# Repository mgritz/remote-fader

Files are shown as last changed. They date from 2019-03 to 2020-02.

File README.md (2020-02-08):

# Remote Fader Firmware for the Datasat AP20 Digital Cinema Audio Processor

## Why is this here?

_Skip if you don't care about fluff._

Well, easy. During my days in university I joined the student cinema group.
As it happened in those days I was able to contribute to the major task of
replacing the outdated analog projection equipment in our theatre with more
up-to-date equipment. Along with a digital projector and some other equipment
we acquired a new Datasat AP20 audio processor.

Long story short, we needed a simple rotary knob _inside_ the cinema theatre for
the supervisor to control the overall volume during a film show while the actual
audio processor sits upstairs in the projector room. Buying the knob from
Datasat was not an option simply because of the hefty price tag.

But we found that Datasat implements a rather simple ASCII based protocol to
handle a whole bunch of settings on their devices and the AP20 has several
interfaces we could use with RS232 being among those. So we traced a cable
through the building...

The first approach was a TI MSP430 Launchpad with an Alps rotary encoder knob
connected that single-directionally transmits ASCII commands to the AP20. But
would't it be cool to have something with also a display?

## What is this?

The coolest type of display we could come up with for a volume control knob to
be used in a dark room is a Nixie tube display.

The PCB in this project connects two digits of IN12b Nixie tubes to an
MSP430G2553. There are two galvanically isolated voltage domains to protect the 
expensive AP20 against surges from the make-shift high voltage supply of the
Nixies.

The application code mainly does two things:
1. Whenever the knob is turned a volume command 'FADER +x\r' is transmitted
   towards the AP20 via UART. That, in turn, causes the AP20 to respond...
2. ... with a 'FADER xx\r' string denominating the current volume level.
   The number is extracted and displayed on the nixies.

Due to poor (but for now, uncorrectable) PCB design choices there must be some
additional glue and safety around the I2C connection between the MSP and the
MAX GPIO expander IC on the other side of the voltage safety barrier.

## Building and Contributing

This is not tested yet and sort of a long running project of mine.
I am using TI Code Composer Studio 8.3 and TI MSP compiler v18.1.5 on Windows
and the programmer-part of the MSP430 Launchpad for debugging.

Documentation for the AP20 and other helpful stuff: \\
http://www.film-tech.com \\
http://www.film-tech.com/warehouse/manuals/TM-H392_V1.2_AP20.pdf

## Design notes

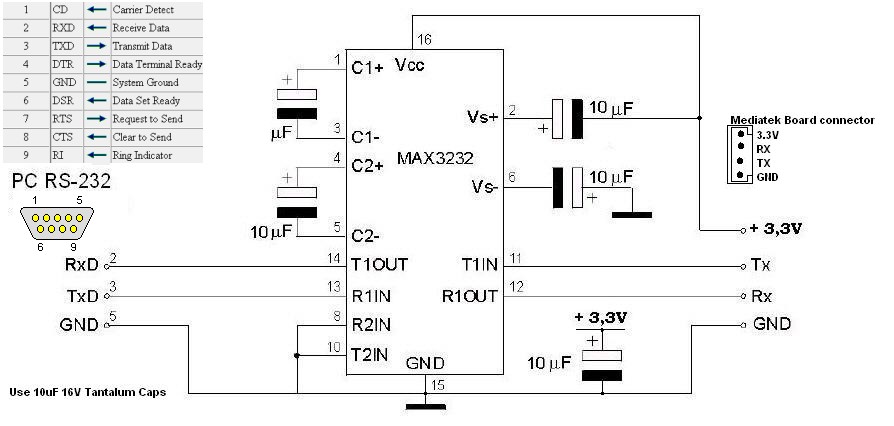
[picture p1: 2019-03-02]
circuit-boards/INTERFACE-MT1389.jpg

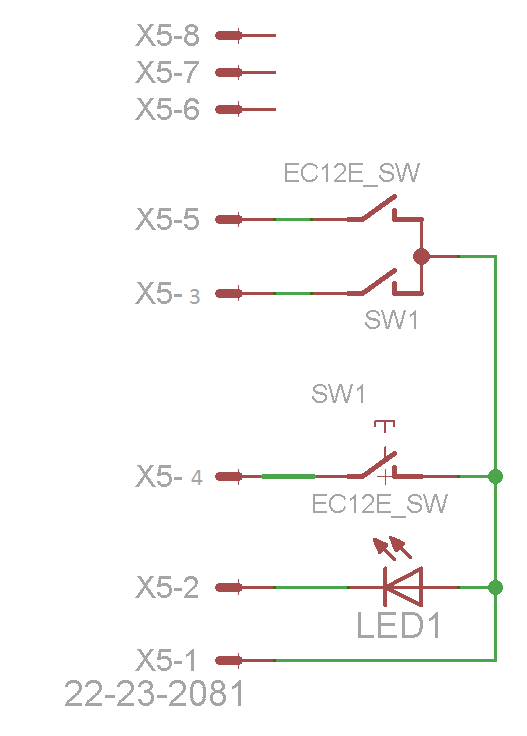
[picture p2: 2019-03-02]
circuit-boards/steckerbelegung.png

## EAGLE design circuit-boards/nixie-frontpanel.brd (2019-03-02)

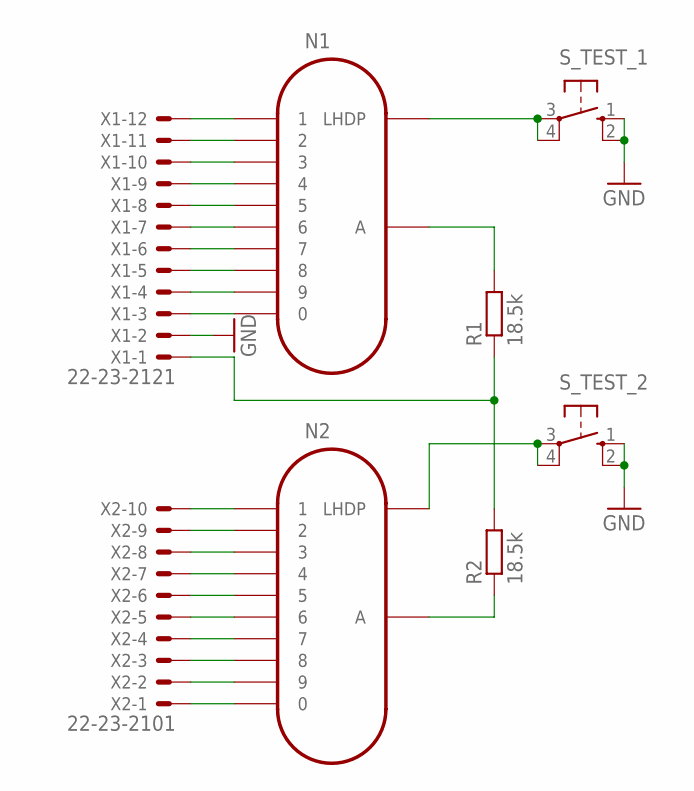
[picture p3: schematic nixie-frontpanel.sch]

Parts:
N1, N2: IN-12B; IN-12
R1, R2: 18.5k; M0805
S_TEST_1, S_TEST_2: 10-XX; B3F-10XX
X1: 22-23-2121
X2: 22-23-2101

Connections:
GND: S_TEST_1.1 (S), S_TEST_1.2 (S1), S_TEST_2.1 (S), S_TEST_2.2 (S1), X1.2
unnamed: N1.1, X1.12
unnamed: N1.2, X1.11
unnamed: N1.3, X1.10
unnamed: N1.4, X1.9
unnamed: N1.5, X1.8
unnamed: N1.6, X1.7
unnamed: N1.7, X1.6
unnamed: N1.8, X1.5
unnamed: N1.9, X1.4
unnamed: N1.0, X1.3
unnamed: N2.1, X2.10
unnamed: N2.2, X2.9
unnamed: N2.3, X2.8
unnamed: N2.4, X2.7
unnamed: N2.5, X2.6
unnamed: N2.6, X2.5
unnamed: N2.7, X2.4
unnamed: N2.8, X2.3
unnamed: N2.9, X2.2
unnamed: N2.0, X2.1
unnamed: R1.1, R2.2, X1.1
unnamed: N1.A, R1.2
unnamed: N2.A, R2.1
unnamed: N1.LHDP, S_TEST_1.3, S_TEST_1.4 (P1)
unnamed: N2.LHDP, S_TEST_2.3, S_TEST_2.4 (P1)

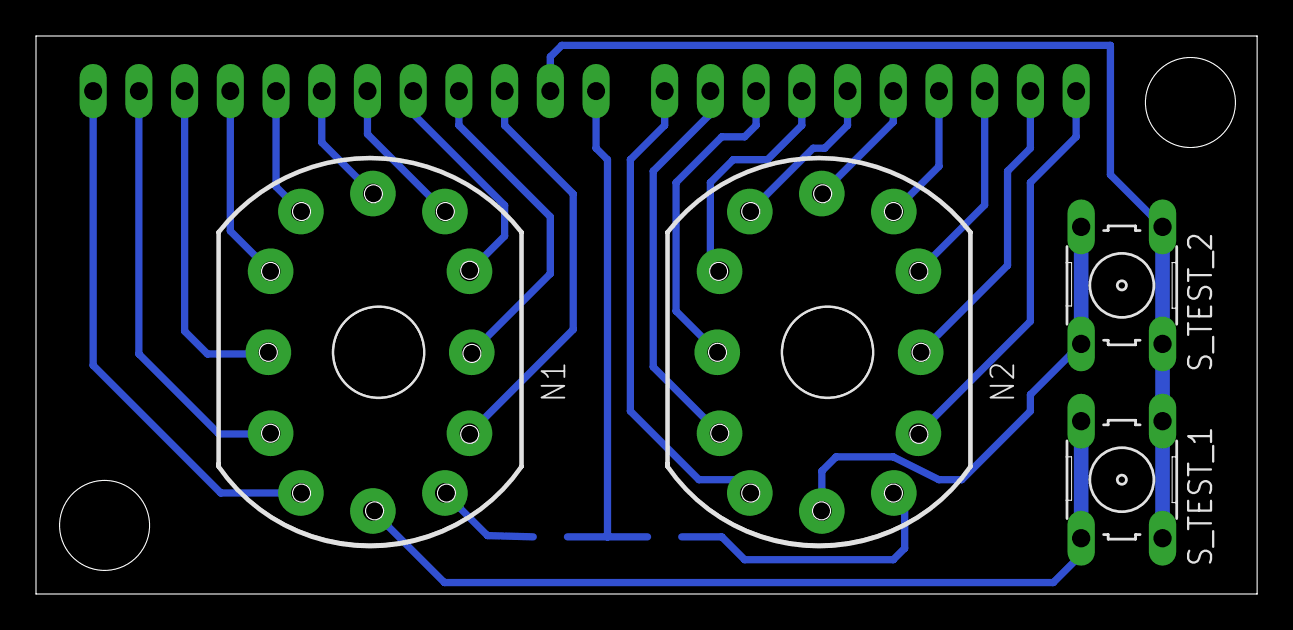
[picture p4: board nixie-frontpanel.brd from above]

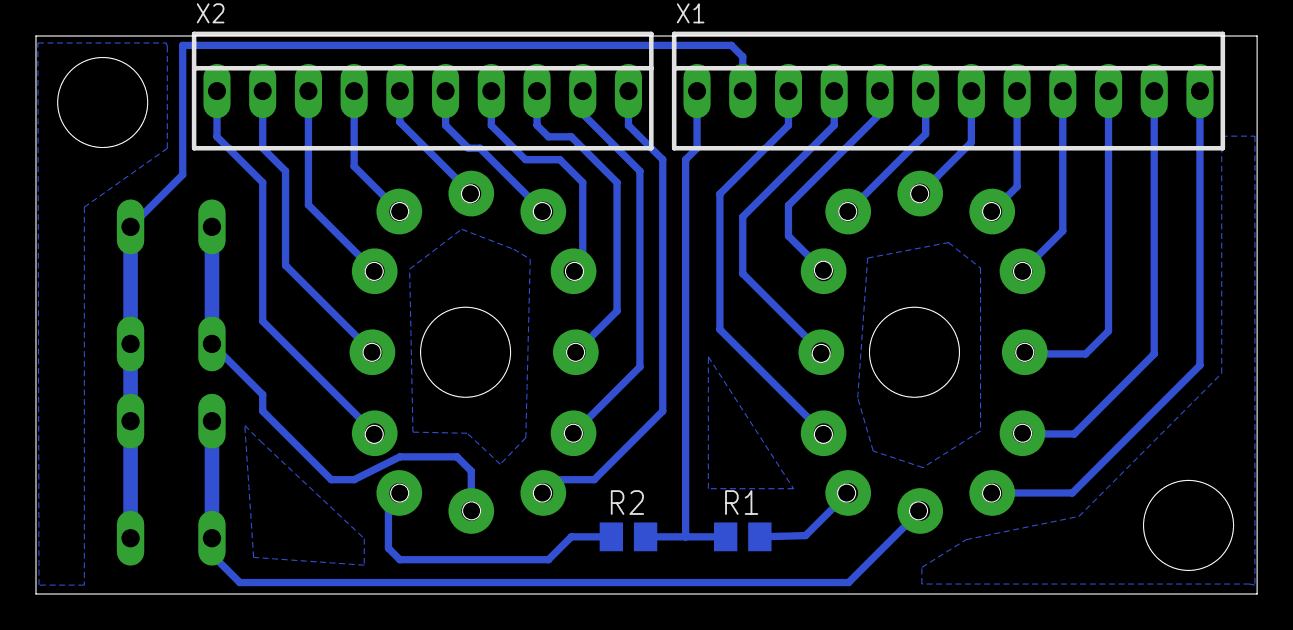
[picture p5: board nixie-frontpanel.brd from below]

Board: 2 copper layers, 67.8 x 31.0 mm, 8 parts (4 on the bottom side), 26 nets.

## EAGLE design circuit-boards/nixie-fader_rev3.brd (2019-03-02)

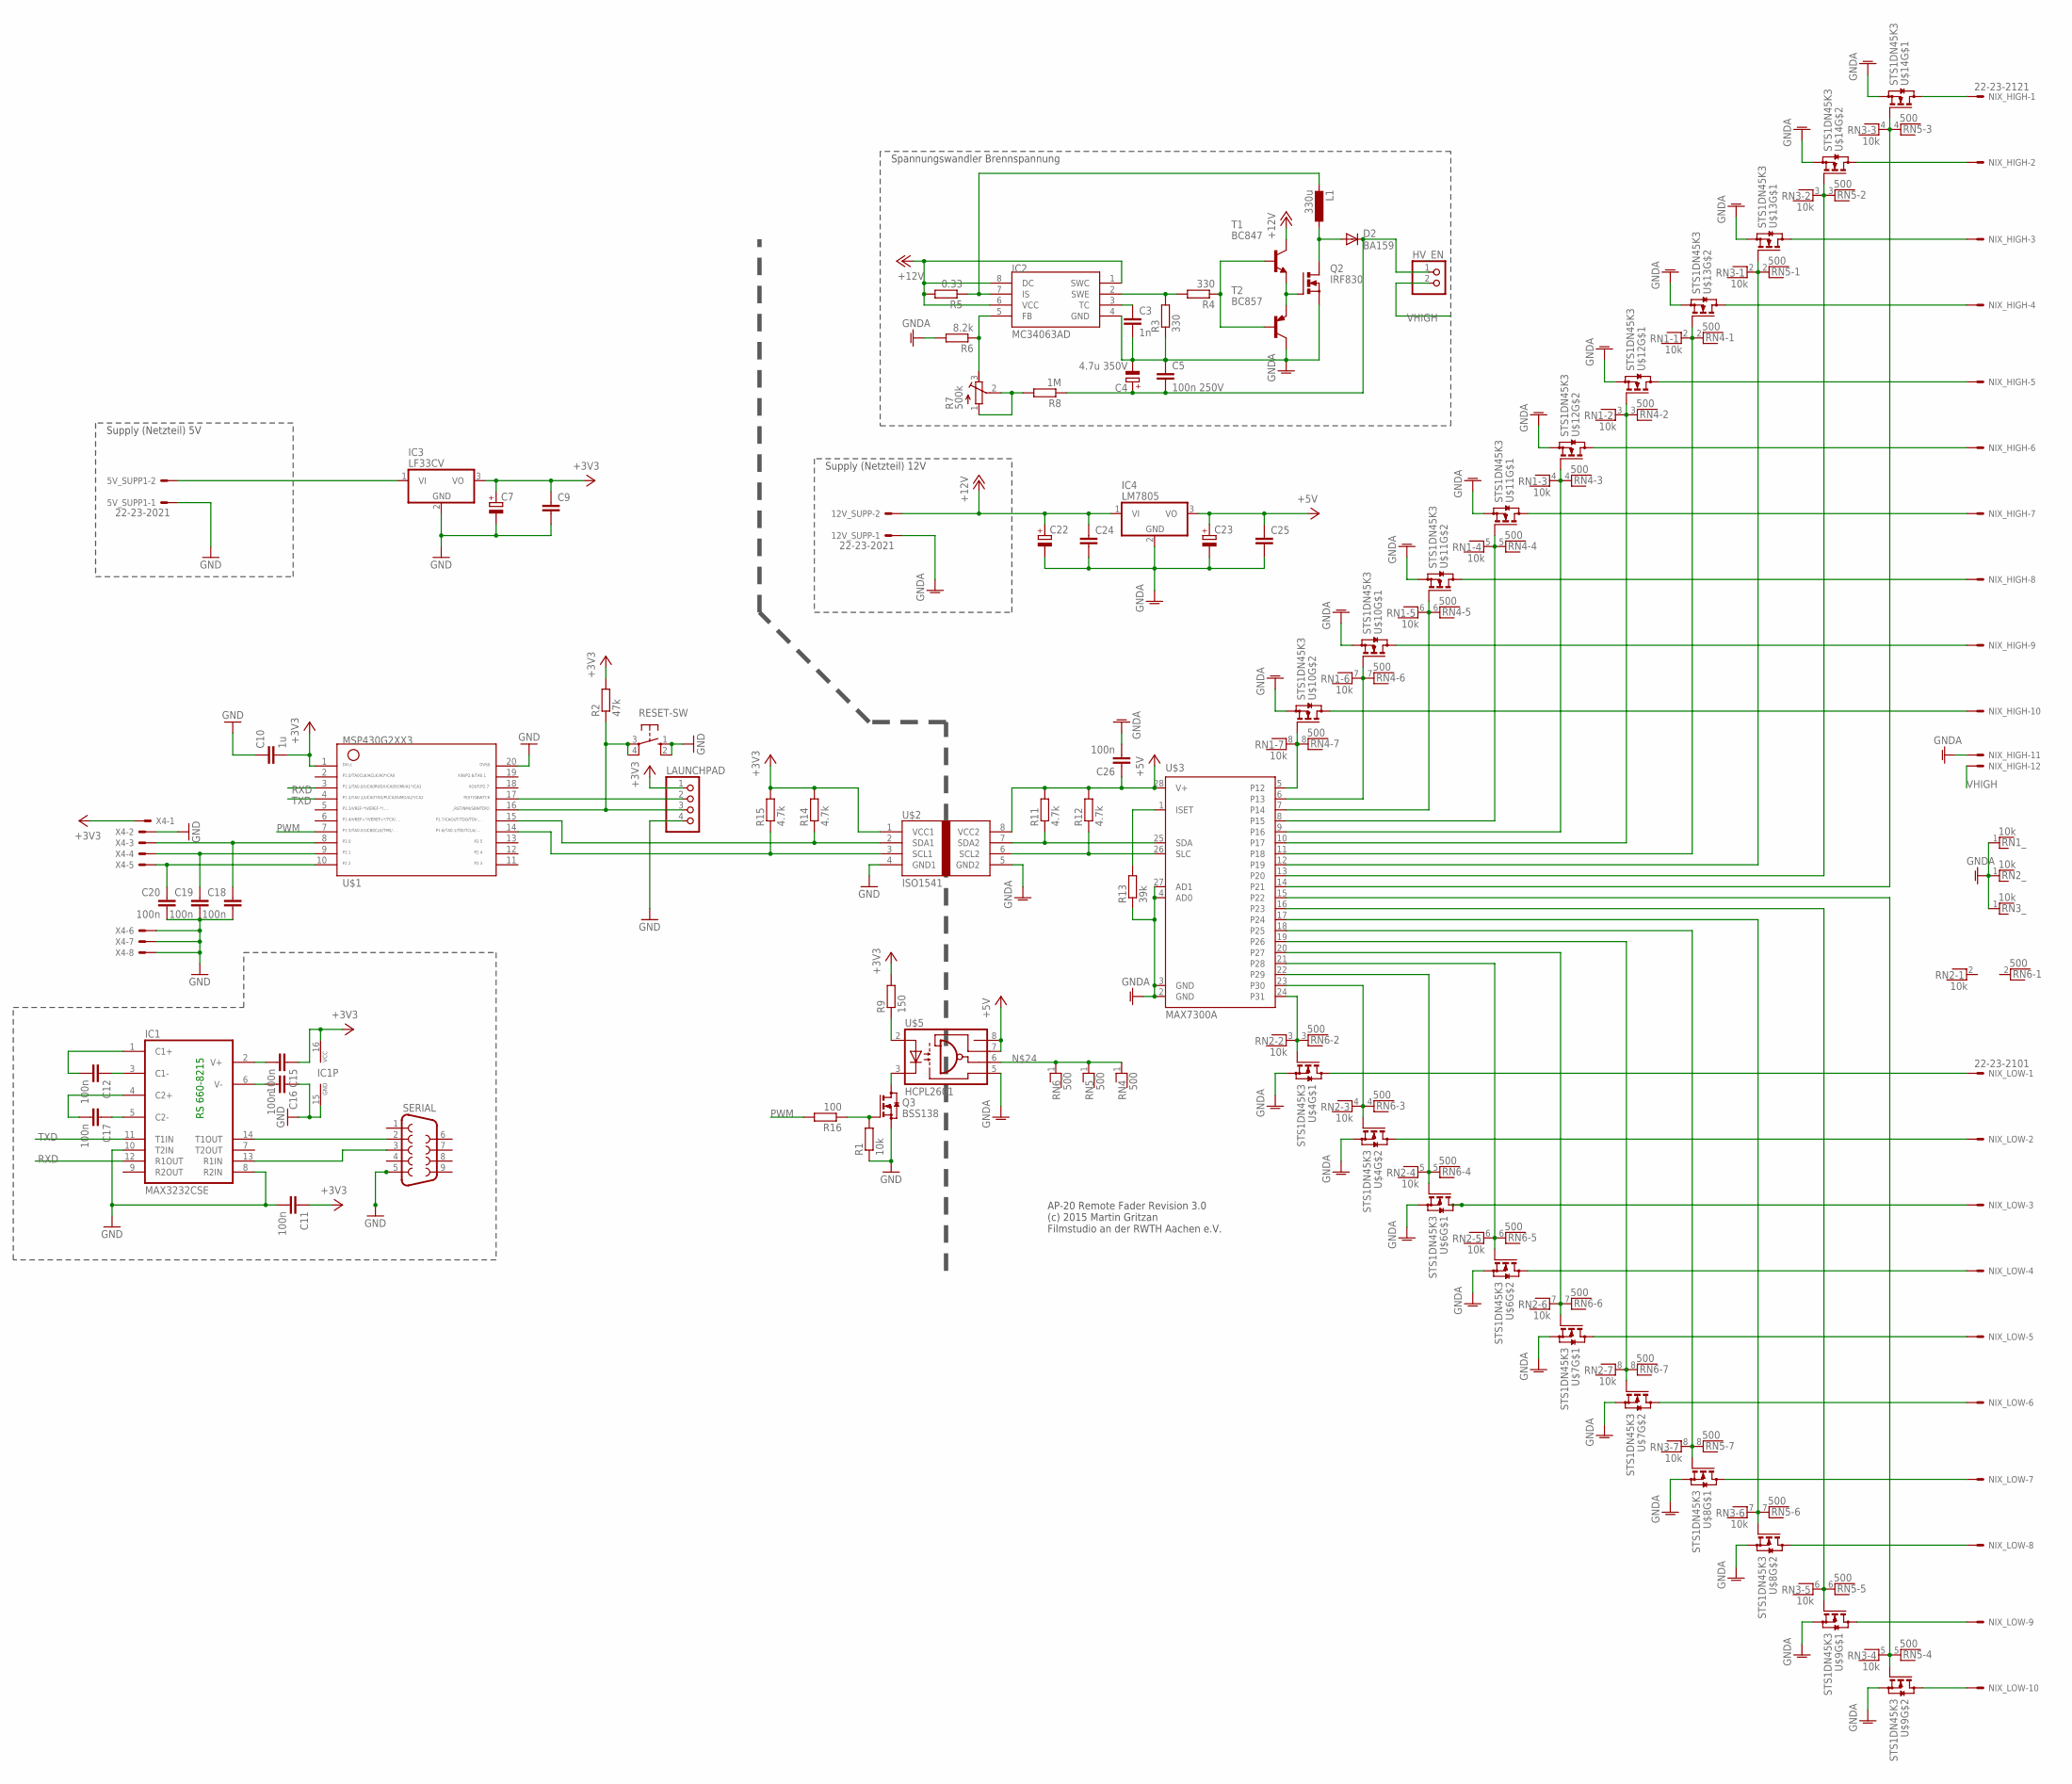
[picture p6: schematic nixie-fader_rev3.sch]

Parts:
5V_SUPP1, 12V_SUPP: 22-23-2021
C3: 1n; C0805
C4: 4.7u 350V; E5-8,5
C5: 100n 250V; C050-024X044
C7, C22, C23: CPOL-EU140CLH-0810; 140CLH-0810
C9, C24, C25: C-EUC0805K; C0805K
C10: 1u; C0805K
C11, C12, C15, C16, C17, C18, C19, C20, C26: 100n; C0805
D2: BA159; P1-10
HV_EN: PINHD-1X2; 1X02
IC1: MAX3232CSE; SO16
IC2: MC34063AD; SOIC8
IC3: LF33CV; TO220V
IC4: LM7805; TO220V
L1: 330u; IRF36
LAUNCHPAD: PINHD-1X4; 1X04
NIX_HIGH: 22-23-2121
NIX_LOW: 22-23-2101
Q2: IRF830; TO220BV
Q3: BSS138; SOT23
R1: 10k; M0805
R2: 47k; R0805
R3, R4: 330; M0805
R5: 0.33; M0805
R6: 8.2k; M0805
R7: 500k; RTRIM3296Y
R8: 1M; M0805
R9: 150; M0805
R11, R12, R14, R15: 4.7k; M0805
R13: 39k; M0805
R16: 100; M0805
RESET-SW: 10-XX; B3F-10XX
RN1, RN2, RN3: 10k; RN-8
RN4, RN5, RN6: 500; RN-8
SERIAL: F09H
T1: BC847; SOT23
T2: BC857; SOT23-BEC
U$1: G2XX3---PW20; PW20
U$2: ISO1541; SOIC8
U$3: MAX7300A; SSOP28
U$4, U$6, U$7, U$8, U$9, U$10, U$11, U$12, U$13, U$14: STS1DN45K3; SO08
U$5: HCPL2601; DIP8-SMD
X4: 22-23-2081

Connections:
+3V3: C7.+, C9.1, C10.2, C11.1, C15.1, IC1.16 (VCC), IC3.3 (VO), LAUNCHPAD.1, R2.2, R9.2, R14.2, R15.2, U$1.1, U$2.1 (VCC1), X4.1
+5V: C23.+, C25.1, C26.1, IC4.3 (VO), R11.2, R12.2, U$2.8 (VCC2), U$3.28 (V+), U$5.7 (EN), U$5.8 (VCC)
+12V: 12V_SUPP.2, C22.+, C24.1, IC2.1 (SWC), IC2.6 (VCC), IC2.8 (DC), IC4.1 (VI), R5.2, T1.3 (C)
GND: 5V_SUPP1.1, C7.-, C9.2, C10.1, C11.2, C16.1, C18.2, C19.2, C20.2, IC1.8 (R2IN), IC1.10 (T2IN), IC1.15 (GND), IC3.2 (GND), LAUNCHPAD.4, Q3.2 (S), R1.1, RESET-SW.1 (S), RESET-SW.2 (S1), SERIAL.5, U$1.20, U$2.4 (GND1), X4.2, X4.6, X4.7, X4.8
GNDA: 12V_SUPP.1, C3.2, C4.-, C5.1, C22.-, C23.-, C24.2, C25.2, C26.2, IC2.4 (GND), IC4.2 (GND), NIX_HIGH.11, Q2.S, R3.1, R6.2, R13.1, RN1.1, RN2.1, RN3.1, T2.C, U$2.5 (GND2), U$3.2 (GND), U$3.3 (GND), U$3.4 (AD0), U$3.27 (AD1), U$4.1 (S), U$4.3 (S), U$5.5 (GND), U$6.1 (S), U$6.3 (S), U$7.1 (S), U$7.3 (S), U$8.1 (S), U$8.3 (S), U$9.1 (S), U$9.3 (S), U$10.1 (S), U$10.3 (S), U$11.1 (S), U$11.3 (S), U$12.1 (S), U$12.3 (S), U$13.1 (S), U$13.3 (S), U$14.1 (S), U$14.3 (S)
unnamed: Q3.1 (G), R1.2, R16.1
unnamed: C12.1, IC1.3 (C1-)
unnamed: C3.1, IC2.3 (TC)
unnamed: IC2.2 (SWE), R3.2, R4.2
unnamed: R4.1, T1.1 (B), T2.B
unnamed: C17.1, IC1.5 (C2-)
unnamed: C17.2, IC1.4 (C2+)
unnamed: C16.2, IC1.6 (V-)
unnamed: C15.2, IC1.2 (V+)
unnamed: LAUNCHPAD.3, R2.1, RESET-SW.3, RESET-SW.4 (P1), U$1.16
unnamed: C12.2, IC1.1 (C1+)
unnamed: R11.1, U$2.7 (SDA2), U$3.25 (SDA)
unnamed: IC1.14 (T1OUT), SERIAL.2
unnamed: R12.1, U$2.6 (SCL2), U$3.26 (SLC)
unnamed: Q2.G, T1.2 (E), T2.E
unnamed: D2.A, L1.1, Q2.D
unnamed: IC2.7 (IS), L1.2, R5.1
unnamed: IC2.5 (FB), R6.1, R7.3 (A)
unnamed: R7.1 (E), R7.2 (S), R8.2
unnamed: C18.1, U$1.8, X4.3
unnamed: RN4.1, RN5.1, RN6.1, U$5.6 (OUT)
unnamed: C19.1, U$1.9, X4.4
unnamed: NIX_HIGH.2, U$14.5 (D), U$14.6 (D)
unnamed: C20.1, U$1.10, X4.5
unnamed: Q3.3 (D), U$5.3 (C)
unnamed: R9.1, U$5.2 (A)
unnamed: RN2.3, RN6.3, U$3.24 (P31), U$4.2 (G)
unnamed: RN1.8, RN4.8, U$3.5 (P12), U$10.4 (G)
unnamed: RN2.4, RN6.4, U$3.23 (P30), U$4.4 (G)
unnamed: RN1.7, RN4.7, U$3.6 (P13), U$10.2 (G)
unnamed: LAUNCHPAD.2, U$1.17
unnamed: RN2.5, RN6.5, U$3.22 (P29), U$6.2 (G)
unnamed: RN2.6, RN6.6, U$3.21 (P28), U$6.4 (G)
unnamed: IC1.13 (R1IN), SERIAL.3
unnamed: R13.2, U$3.1 (ISET)
unnamed: RN1.6, RN4.6, U$3.7 (P14), U$11.4 (G)
unnamed: RN2.7, RN6.7, U$3.20 (P27), U$7.2 (G)
unnamed: RN2.8, RN6.8, U$3.19 (P26), U$7.4 (G)
unnamed: RN1.5, RN4.5, U$3.8 (P15), U$11.2 (G)
unnamed: RN3.8, RN5.8, U$3.18 (P25), U$8.2 (G)
unnamed: RN3.7, RN5.7, U$3.17 (P24), U$8.4 (G)
unnamed: RN1.4, RN4.4, U$3.9 (P16), U$12.4 (G)
unnamed: RN3.6, RN5.6, U$3.16 (P23), U$9.2 (G)
unnamed: RN3.5, RN5.5, U$3.15 (P22), U$9.4 (G)
unnamed: NIX_HIGH.1, U$14.7 (D), U$14.8 (D)
unnamed: NIX_LOW.1, U$4.7 (D), U$4.8 (D)
unnamed: NIX_LOW.2, U$4.5 (D), U$4.6 (D)
unnamed: R14.1, U$1.15, U$2.2 (SDA1)
unnamed: NIX_LOW.3, U$6.7 (D), U$6.8 (D)
unnamed: NIX_LOW.4, U$6.5 (D), U$6.6 (D)
unnamed: NIX_LOW.5, U$7.7 (D), U$7.8 (D)
unnamed: NIX_LOW.6, U$7.5 (D), U$7.6 (D)
unnamed: NIX_LOW.7, U$8.7 (D), U$8.8 (D)
unnamed: NIX_LOW.8, U$8.5 (D), U$8.6 (D)
unnamed: NIX_LOW.9, U$9.7 (D), U$9.8 (D)
unnamed: R15.1, U$1.14, U$2.3 (SCL1)
unnamed: NIX_LOW.10, U$9.5 (D), U$9.6 (D)
unnamed: RN1.3, RN4.3, U$3.10 (P17), U$12.2 (G)
unnamed: RN1.2, RN4.2, U$3.11 (P18), U$13.4 (G)
unnamed: RN3.2, RN5.2, U$3.12 (P19), U$13.2 (G)
unnamed: RN3.3, RN5.3, U$3.13 (P20), U$14.4 (G)
unnamed: 5V_SUPP1.2, IC3.1 (VI)
unnamed: RN3.4, RN5.4, U$3.14 (P21), U$14.2 (G)
unnamed: NIX_HIGH.3, U$13.7 (D), U$13.8 (D)
unnamed: NIX_HIGH.4, U$13.5 (D), U$13.6 (D)
unnamed: NIX_HIGH.5, U$12.7 (D), U$12.8 (D)
unnamed: NIX_HIGH.6, U$12.5 (D), U$12.6 (D)
unnamed: NIX_HIGH.7, U$11.7 (D), U$11.8 (D)
unnamed: NIX_HIGH.8, U$11.5 (D), U$11.6 (D)
unnamed: NIX_HIGH.9, U$10.7 (D), U$10.8 (D)
unnamed: NIX_HIGH.10, U$10.5 (D), U$10.6 (D)
PWM: R16.2, U$1.7
RXD: IC1.12 (R1OUT), U$1.3
TXD: IC1.11 (T1IN), U$1.4
VHIGH: HV_EN.2, NIX_HIGH.12
VHIGH_SUP: C4.+, C5.2, D2.C, HV_EN.1, R8.1

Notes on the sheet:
Supply (Netzteil) 12V
Spannungswandler Brennspannung
RS 660-8215
AP-20 Remote Fader Revision 3.0 (c) 2015 Martin Gritzan Filmstudio an der RWTH Aachen e.V.
Supply (Netzteil) 5V

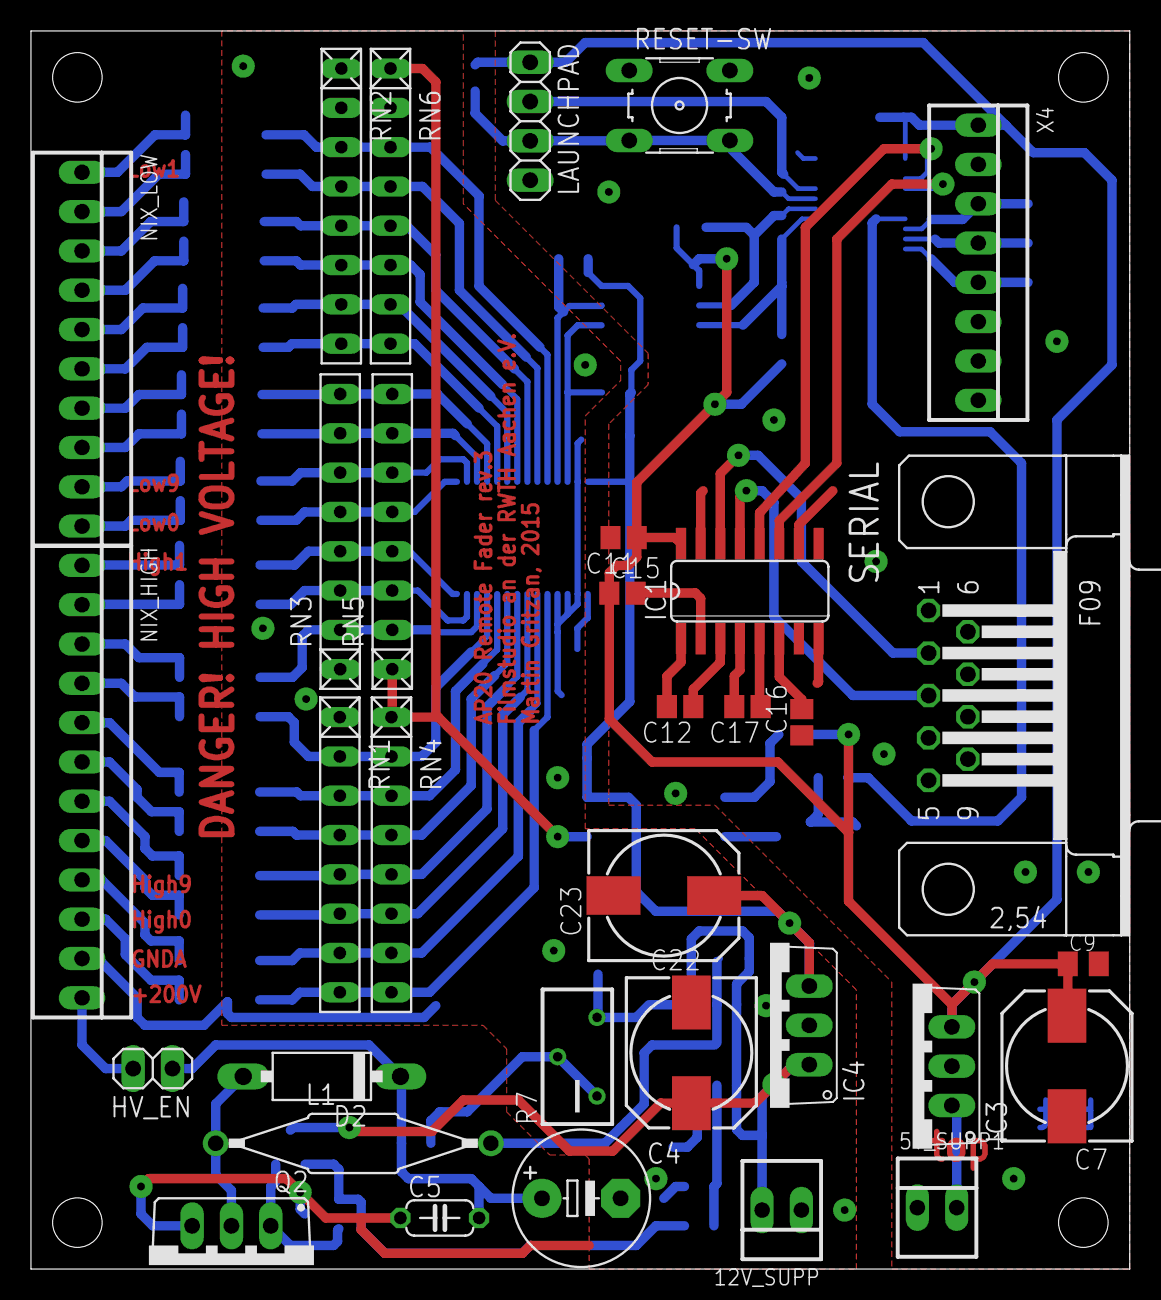
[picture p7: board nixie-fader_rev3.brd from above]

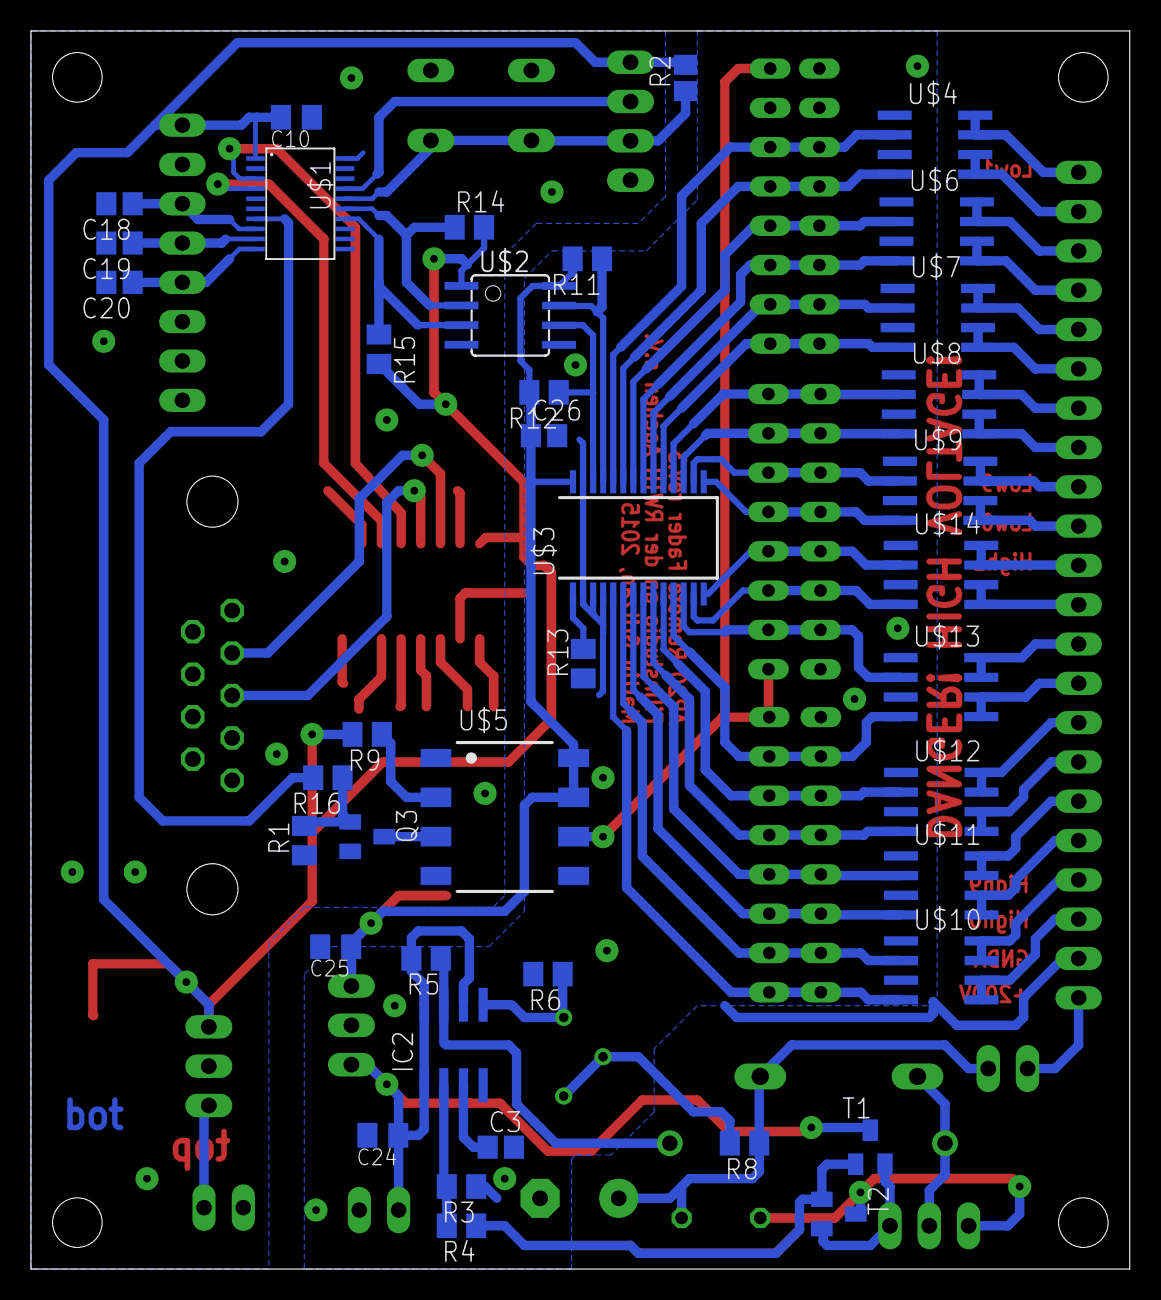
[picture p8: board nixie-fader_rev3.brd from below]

Board: 2 copper layers, 71.0 x 80.0 mm, 73 parts (40 on the bottom side), 81 nets.

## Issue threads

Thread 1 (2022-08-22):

Bugreports

UrbanJacobs, 2022-08-22:
Muss leider mit ein paar Bugreports nerven:
* Vor den Kommandos fehlt ein '@'. Ohne das versteht der AP20 sie nicht.
* Die Firmware überprüft die Lautstärke nicht. Und erwartungsgemäß sagt der AP20 nicht von selbst auf dem UART Bescheid, wenn die Lautstärke vom Vorführraum aus geändert wird.
* Dass die Anzeige aus bleibt, bis man einen Fader-Level schickt, funktioniert nicht immer. Manchmal leuchten schon beim Einschalten random Zahlen auf.

Dann noch eine Frage:
* Geht die Anzeige eigentlich irgendwann wieder aus, oder bleibt sie "für immer" an, solange der Strom an ist? Inzwischen wird nämlich der Partyknopf nicht mehr gedrückt, weil die Uni den Beamer auch nutzen möchte, da es gelegentlich Probleme mit dem Hörsaalbeamer gibt. Wäre daher ggf. ein Feature sinnvoll, dass die Anzeige nach 3 Stunden ohne Änderung ausgeht, und dann beim ersten empfangenen Fader-Level wieder an?

mgritz, 2022-08-23:
@UrbanJacobs PR Welcome :wink:

UrbanJacobs, 2022-10-03:
Dazu muss ich erst mal pushen dürfen ;)

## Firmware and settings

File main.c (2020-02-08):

#include <msp430.h> 
#include "msp430g2553.h"

#include "nixie-disp.h"
#include "ap20-ifc.h"
#include "alps-knob.h"

static inline void
clockInit(void) {
	/* Setting clocks to:
	 * MCLK = SMCLK = 1MHz
	 * ACLK = 12kHz
	 */
    DCOCTL = CALDCO_1MHZ;		// set DCO to 1MHz
    BCSCTL1 = CALBC1_1MHZ;		// set DCO Range Sel correctly
    BCSCTL1 |= DIVA_0;			// ACLK-divider off
    BCSCTL2 = SELM_0 + DIVM_0 + DIVS_0; // MCLK <- DCO, clock input dividers off


    BCSCTL3 = LFXT1S_2;		// source ACLK from internal VLO @ 12kHz / divider
//    BCSCTL3 = LFXT1S_0 + XCAP_3; // source ACLK from external 32762Hz-osc.
    __delay_cycles(800000);
}

volatile char lastFaderLevel = 1;

int
main(void) {
    WDTCTL = WDTPW | WDTHOLD;	// Stop watchdog timer

    clockInit();
    ap20_init();
    knob_setup();
    __enable_interrupt();

    while(1){
        /* see if the AP20 gave something over UART */
        ap20_process_bytes();
        const uint8_t current_lvl = ap20_current_level();
    	if(current_lvl != lastFaderLevel){
    		nixieWrite(current_lvl);
    	}
    	lastFaderLevel = current_lvl;

    	const int8_t increments = knob_get_changes();
    	if (increments != 0) {
    		ap20_change_level(increments);
    	}
    }
}

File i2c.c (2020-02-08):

#include "i2c.h"

#include "msp430g2553.h"

#include "port-helpers.h"

#define SCL BIT6
#define SDA BIT7

static volatile unsigned char i2c_fault = 0;


/** Use Timer A0 to safeguard I2C access for hangups. */
static inline void
TA0Init(void)
{
	/* Timer runs @ 1500Hz */
	TA0CTL = TASSEL_1 + ID_3 + MC_0; // ACLK is source, divider /8, timer halted
	TA0CCR0 = 750;	// .5 sec at this timer frequ.
	TACCTL0 = CCIE; // Capture/Compare 0 Interrupt Enable
}

/** Start TA0 now. */
static inline void
TA0_START(void)
{
    TA0R = 0;
    TA0CTL |= MC0;
}

/** Stop TA0 now. */
static inline void
TA0_STOP(void)
{
    TA0CTL &= ~MC0;
}
/** ISR for timer-based anti-beat */
#pragma vector=TIMER0_A0_VECTOR
__interrupt void TA0_A0_ISR(void) {
	TA0_STOP();
	i2c_fault = 1;
	__bic_SR_register_on_exit(CPUOFF);	//exit LPM
}

void i2cSetup(int Adress){
	// Pulse SCL 9 times to bring slave into defined state

	PIN_setModeGPO(P1, SCL);
	PIN_setModeGPI_nopull(P1, SDA);
	for (int i = 9; (i > 0) && (!PIN_readIn(P1, SDA)); i--)
	{
		PIN_outHigh(P1, SCL);
		__delay_cycles(1);// If F_CPU = 1MHz this should be equivalent to 250kHz.
		PIN_outLow(P1, SCL);
		__delay_cycles(1);
	}
	PIN_setModeGPO(P1, SDA);
	PIN_outLow(P1, SDA);
	PIN_outHigh(P1, SCL);
	__delay_cycles(1);
	PIN_outHigh(P1, SDA);

	// Setup actual I2C module
    PIN_setModeSecPeriph(P1, SCL | SDA);
	UCB0CTL1 |= UCSWRST;				//stop UCB0
	UCB0CTL0 = UCMST + UCMODE_3 + UCSYNC;		//configure UCB0
	UCB0CTL1 = UCSSEL_2 + UCSWRST;
	UCB0BR0 = 2;					//frequency divider for ca. 1MHz /
	UCB0BR1 = 0;
	UCB0I2CSA = Adress;				//set sensor's I2C address
	UCB0CTL1 &= ~UCSWRST;				//start UCB0
	IE2 |= UCB0TXIE + UCB0RXIE;		//enable TX and RX interrupts

	TA0Init();
}

static volatile unsigned char TransmittedData;
static volatile int WriteMode = 0;
static volatile int phase = 0;
static volatile unsigned char WriteRegister;
static volatile char wdtHold = 0;

void i2cWrite(int Adress, int Value){
	while (UCB0CTL1 & UCTXSTP);			//check if STOP is sent
	WriteMode = 1;						//important for the ISR procedure
	WriteRegister = Adress;
	TransmittedData = Value;
	phase = 0;					//important for ISR procedure

	IE2 &= ~UCB0RXIE;			//clear RX interrupt-enable...
	IE2 |= UCB0TXIE;			//... and set TX interrupt-enable

	UCB0CTL1 |= UCTR + UCTXSTT;	//send START condition + address + Write
	TA0_START();
	__bis_SR_register(CPUOFF + GIE);	//go into a LPM and wait for ISR
	TA0_STOP();
}

volatile static unsigned char ReceivedData;

unsigned char i2cRequest(unsigned char Register){
	TransmittedData = Register;
	WriteMode = 0;			//important for ISR procedure
	phase = 0;				//important for ISR procedure
	IE2 &= ~UCB0RXIE;		//clear RX interrupt-enable
	IE2 |= UCB0TXIE;		//set TX interrupt-enable

	while (UCB0CTL1 & UCTXSTP);		//ensure STOP condition was sent
	UCB0CTL1 |= UCTR + UCTXSTT;		//send START condition + address + Write
	TA0_START();
	__bis_SR_register(CPUOFF + GIE);//go into a LPM and wait for ISR
	TA0_STOP();

	if (i2c_fault) {
		return 0;
	}

	while (UCB0CTL1 & UCTXSTP);		//ensure STOP was sent
	return ReceivedData;
}


#pragma vector = USCIAB0TX_VECTOR
__interrupt void USCIAB0TX_ISR(void)
{
	if(WriteMode){
		if(phase == 0){
			UCB0TXBUF = WriteRegister;		//put the register address on the bus
			phase = 1;

		}
		else if (phase == 1){
			phase = 2;
			UCB0TXBUF = TransmittedData;		//put data on the bus

		}
		else if(phase == 2){
			IFG2 &= ~(UCB0TXIFG + UCB0RXIFG);	//disable RX and TX interrupts
			UCB0CTL1 |= UCTXSTP;				//send STOP condition
			__bic_SR_register_on_exit(CPUOFF);	//exit LPM
			WriteMode = 0;
			phase = 0;
		}
	}
	else{
		//Read-mode
		if(phase == 0){
			UCB0TXBUF = TransmittedData;		//put register address on the bus
			phase = 1;
		}
		else if (phase == 1){
			IE2 &= ~UCB0TXIE;			//disable TX interrupts
			IE2 |= UCB0RXIE;			//enable RX interrupts

			UCB0CTL1 &= ~UCTR;			//clear UCTR bit (means READ mode on next START condition)
			UCB0CTL1 |= UCTXSTT;			//send START condition

			while (UCB0CTL1 & UCTXSTT);			//wait for START to be sent
			UCB0CTL1 |= UCTXSTP;			//send STOP condition and wait for the sensor-data
			phase = 2;
		}
		else if (phase == 2){
			ReceivedData = UCB0RXBUF;		//read sensor-data from the bus
			IFG2 &= ~(UCB0TXIFG + UCB0RXIFG);	//disable interrupts
			__bic_SR_register_on_exit(CPUOFF);	//exit LPM
		}
	}
}

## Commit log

2019-03-02 Initial Commit
    There already is a lot of stuff here because of ongoing development.
    Problems are marked in the files and will be fixed down the line.
    [main.c, uartbuf.c]
2019-03-02 PCBs added
    Those are the EAGLE files. Made with EAGLE 7 or so, too long ago
    for me to remember exactly.
    [nixie-fader_rev3.brd, nixie-fader_rev3.sch, nixie-frontpanel.brd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]
2019-03-02 add picture of knob connection
    This is the way the ALPS knob is meant to be connected to the PCB input.
2019-03-16 moved ALPS knob functionality into separate files
    Added some thread safety around getting the knob increments
    instead of having this directly transmit the UART.
    Also moove sys clock init to main.c - makes more sense there.
2019-03-16 move nixie stuff into own file
    re-enable uart and hopefully fix race condition in level handling.
    [main.c, nixie-disp.c]
2019-03-31 change uartbuf to use UFW ring-buffer
    changed C dialect to -C99 and set NDEBUG to make it
    compile without the 'assert' (that wouldn't fit into
    memory).
    Removed the state machine for parsing the input.
    That is to be done in a different module.
2019-11-24 move i2c out of header
2020-02-08 use SDA-aware I2C recovery protocol
    As suggested in this AN
    https://www.analog.com/media/en/technical-documentation/application-notes/54305147357414AN686_0.pdf
    The I2C recovery should check the SDA's state to quit recovering the slave
    as early as possible and to ensure proper STOP condition has been sent.
2020-02-08 knob: revert away from IRQ-based debounce
    That TimerA0 stuff wasn't working anyway so, lets get rid of it.
    We can wait with a short busy loop instead.
    Cannot test it, though.
2020-02-08 use Timer to safeguard I2C transaction
    The application must stay responsive even if the I2C
    got stuck due to slave not being powered.
    So we safeguard this with a timer interrupt.
    [i2c.c]
2020-02-08 nixie: re-init before each write
    Re-initialize I2C and the external GPIO expander
    because we have no way of knowing whether the 12V
    rail may have been power-cycled since the last
    write cycle.
2020-02-08 nixie: switch digit outputs
    ... for more convenient mounting.
2020-02-08 uart: allow sending const buffers
2020-02-08 knob: cleanup and re-enable
    Clean up this file a bit. Remove superflous
    method, switch to underscore naming
    everywhere and remove residue of the old
    timer-driven de-bounce.
    Reconnect increments from the knob to sending
    data to the AP20 interface's empty transmit
    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
